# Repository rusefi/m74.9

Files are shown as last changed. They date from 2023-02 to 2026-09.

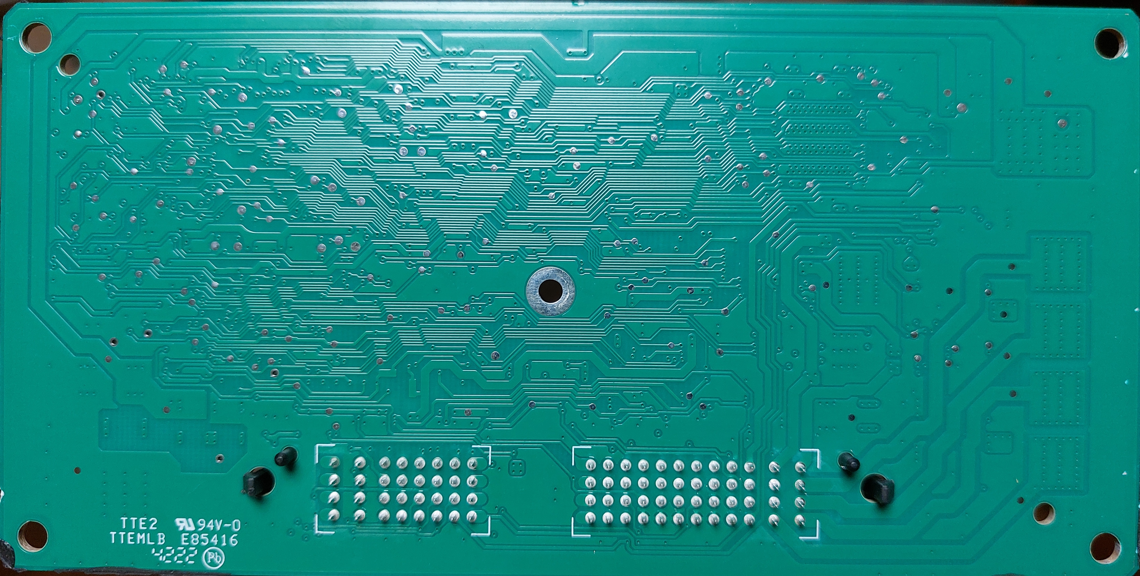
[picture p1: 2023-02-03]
hardware/photos/back.jpg

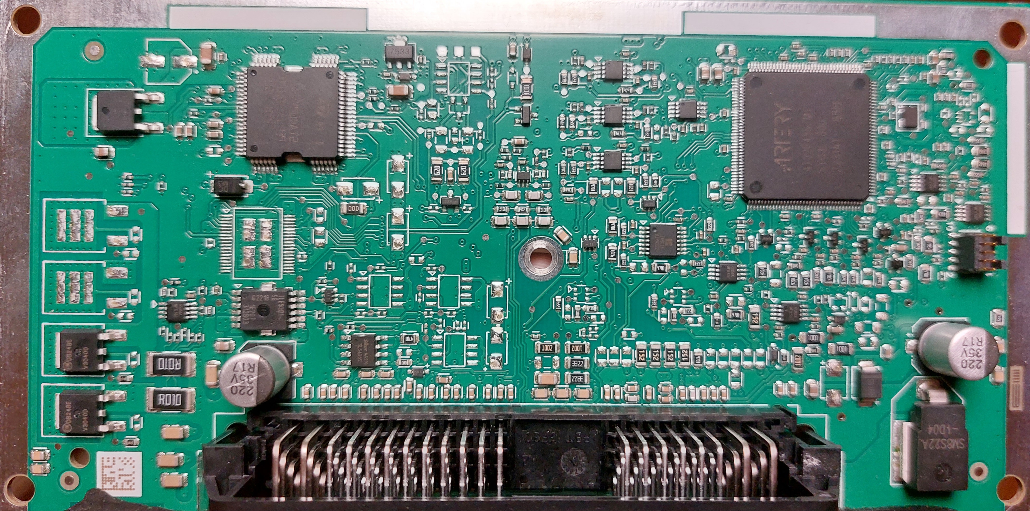
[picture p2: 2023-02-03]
hardware/photos/front3.jpg

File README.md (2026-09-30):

# m74.9

Reverse engineering of m74.9 ECU using KiCad EDA

[Interactive Pinout](https://rusefi.com/docs/pinouts/m74.9/)

See also https://github.com/rusefi/S105

* 8450086873 Niva
* 8450086874 Niva
* 8450110707 Granta (wasted spark)
* 8450043732 Vesta NG (individual spark) 
* 259.3765 004-01 Gaz
  
## Инструкции по разборке

Помимо очевидных четырёх винтов, 🔴пятый винт🔴 прикрепляет печатную плату к НИЖНЕЙ половине корпуса. Рекомендуем сначала сломать клей по периметру корпуса, а потом отделить основной разъём от верхней половины корпуса. Нагрев феном очень помогает!

WhatsApp Image 2024-01-13 at 11 08 42_85430087

WhatsApp Image 2024-01-13 at 11 15 42_073bf53d

## PCB

[Higher resolution photos click here](https://github.com/rusefi/m74.9/tree/main/hardware/photos)









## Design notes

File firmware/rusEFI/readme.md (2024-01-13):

See https://rusefi.com/build_server/rusefi_bundle_m74_9.zip

See https://github.com/rusefi/rusefi/tree/master/firmware/config/boards/m74_9

## flags

Itelma uses custom user system area flags e.g. "fuses".

rusEFI likes RAM we go with default user system area flags e.g. "fuses".

fuses-default.bin - default user area dump extracted from AT32F435-START with default RAM vs FLASH cache configuration:
384 Kb of RAM + 256Kb for cache for zero-wait flash

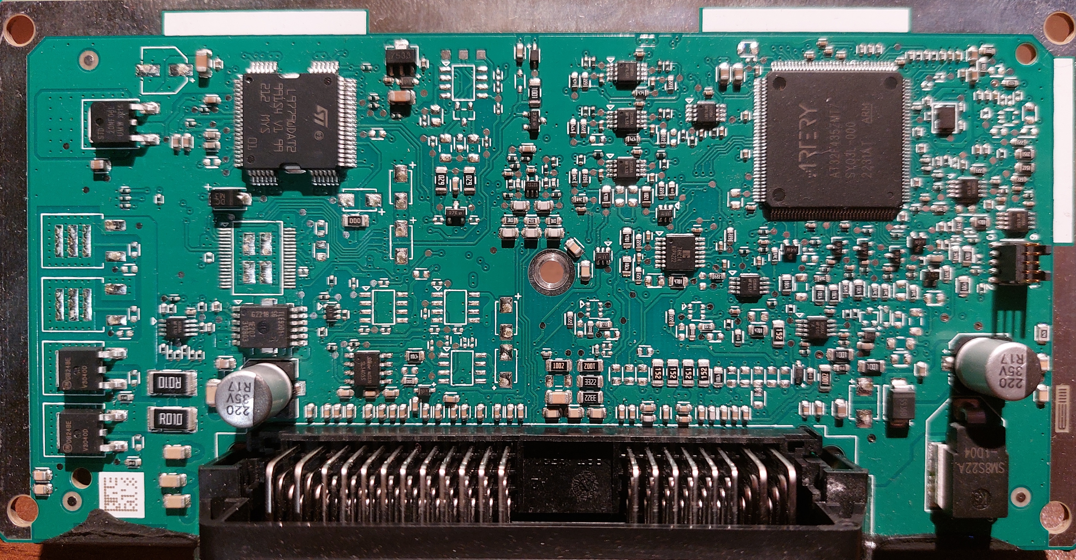
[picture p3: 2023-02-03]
hardware/photos/front1.jpg

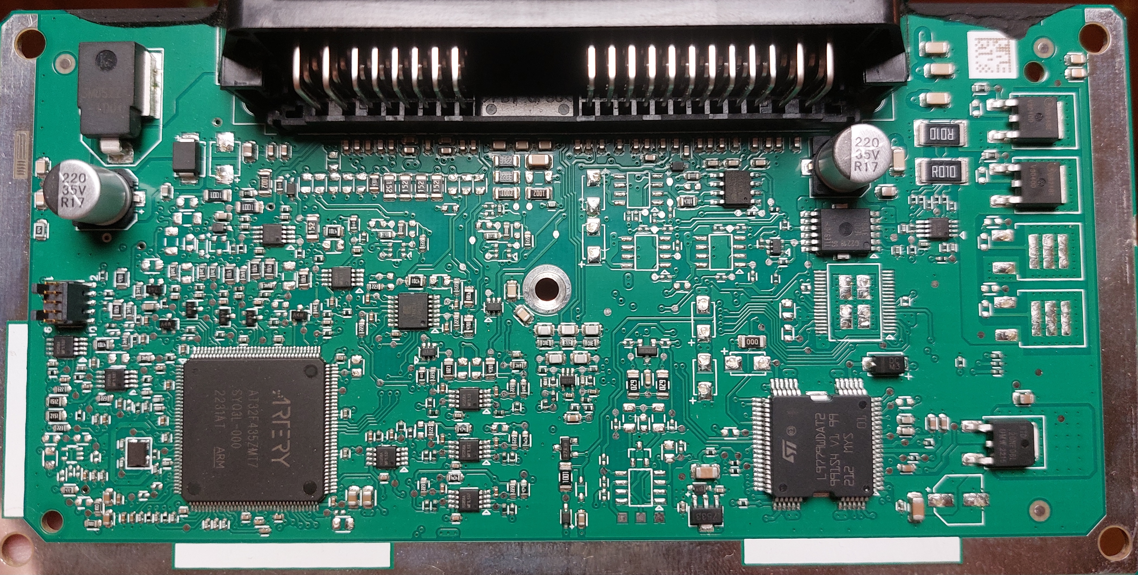
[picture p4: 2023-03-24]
hardware/photos/front2.jpg

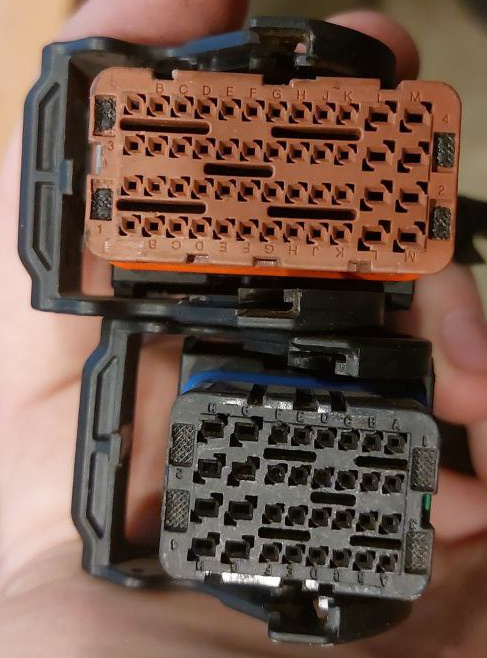
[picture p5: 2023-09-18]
oem-plugs.jpg

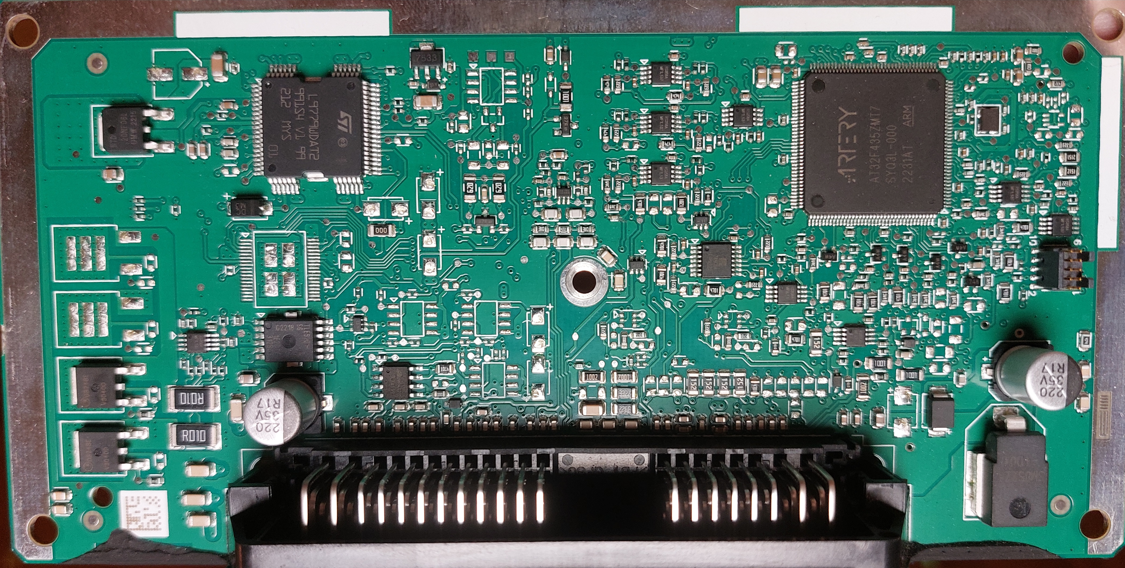
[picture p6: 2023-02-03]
m74.9_front_3.jpg

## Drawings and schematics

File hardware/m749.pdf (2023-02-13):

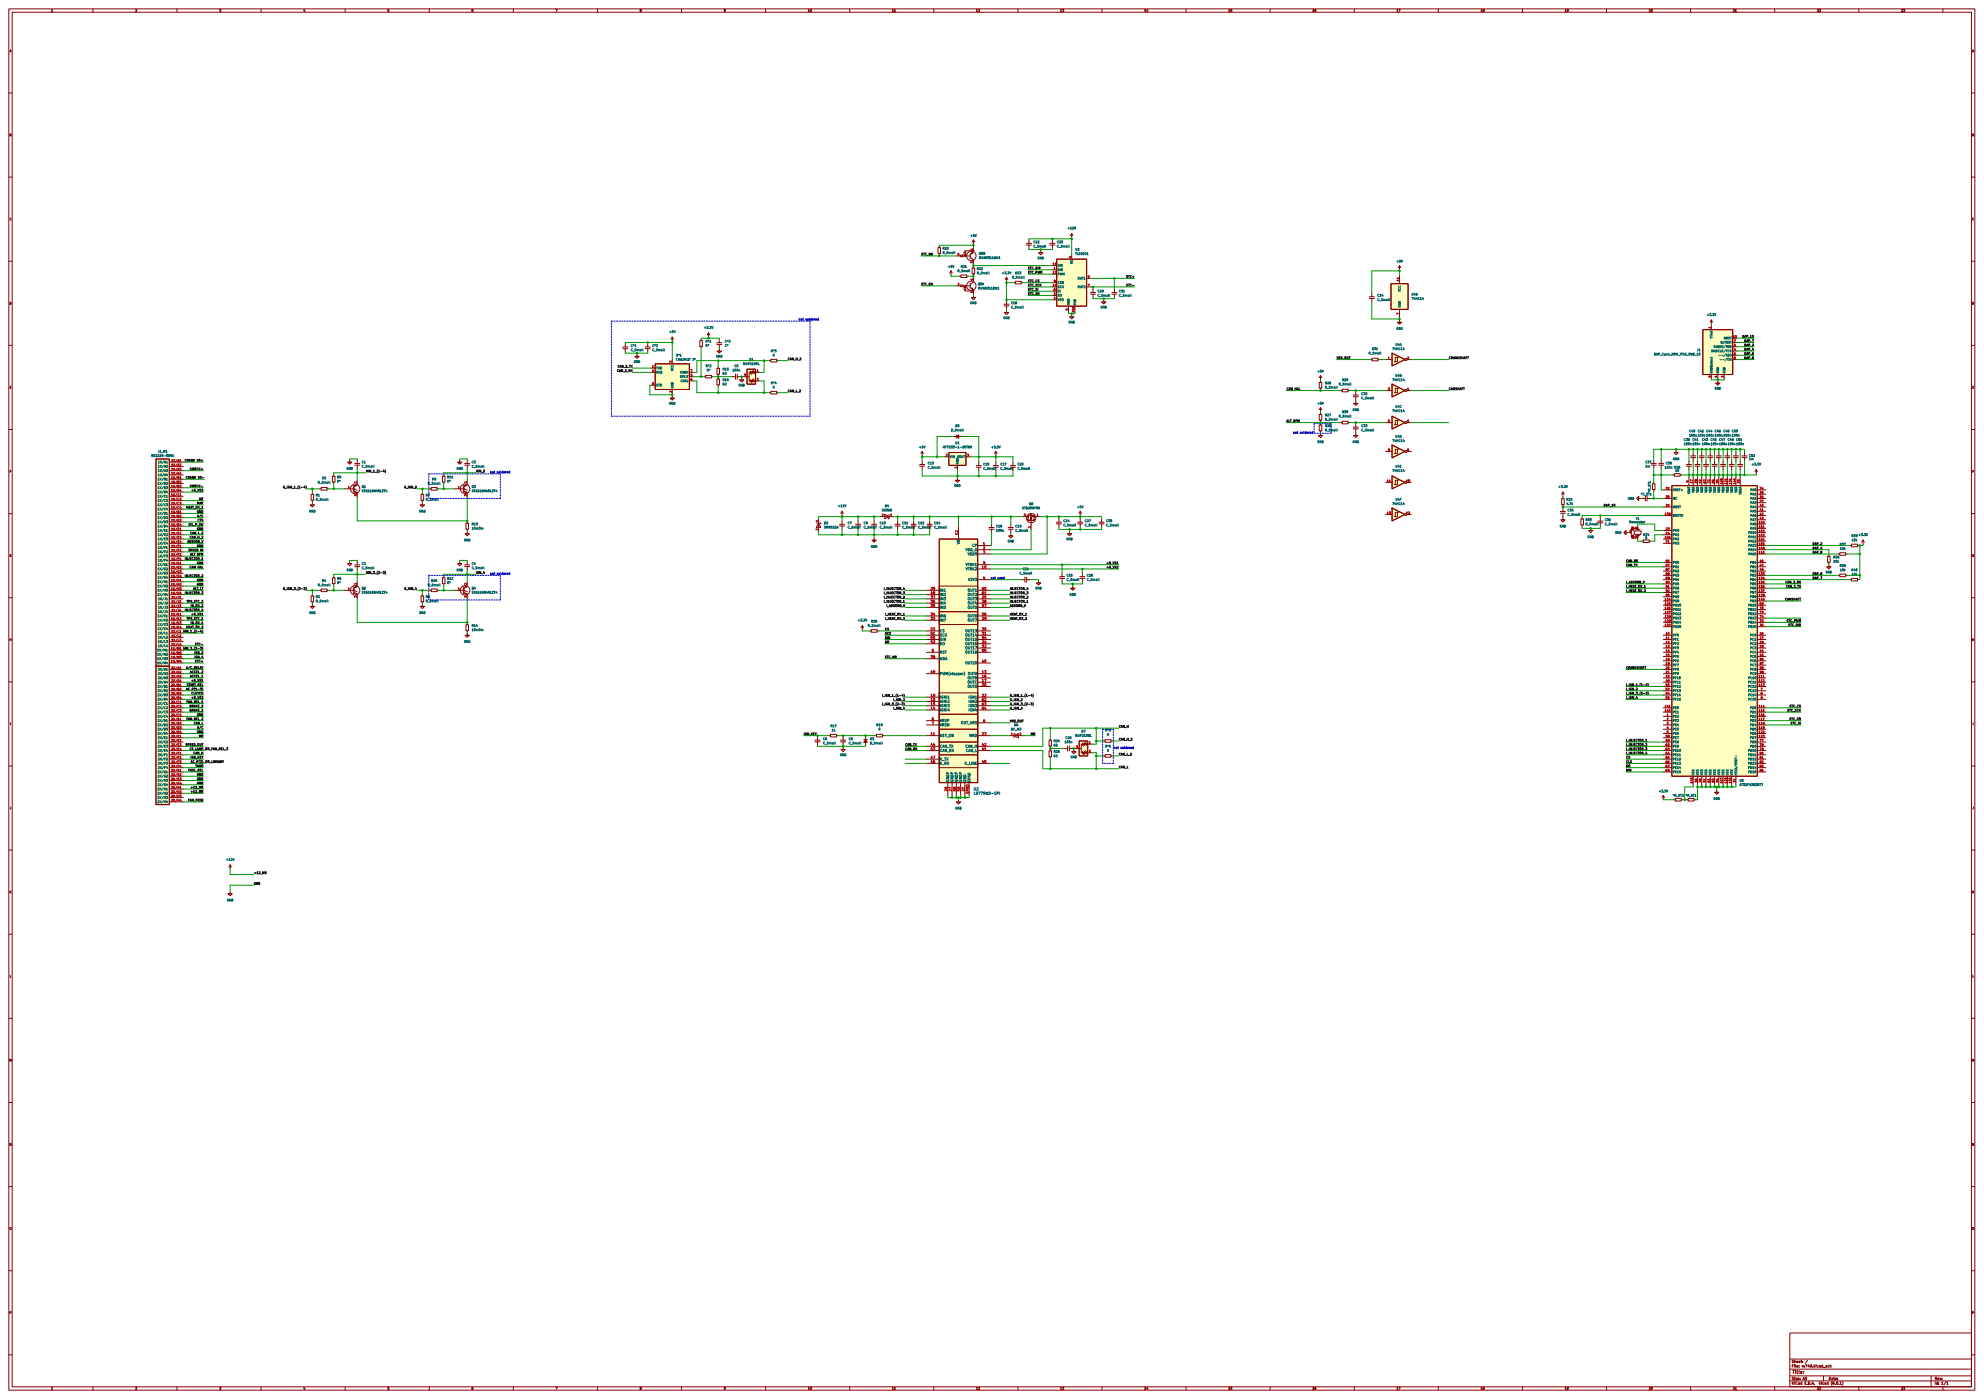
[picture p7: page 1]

IAT GND MAP CRANK VR+ CRANK VR- KNOCK+ KNOCK- HEAT_OX_1 A/C

OUT4 | 25 GNDP 26 GNDP 27

64 VRSN

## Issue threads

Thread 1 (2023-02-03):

at32f435zmt7 is not 100% pin compatible with stm32

rusefillc, 2023-02-03:
at32f435zmt7 is not 100% pin compatible with stm32

i suggest we start with official stm32 symbol and make changes to highlight all the pins which differ

rusefillc, 2023-02-04:
at32f435zmt7 отличается от stm32f437zit6 в пяти местах
30 stm - vdd, at - nc
31 stm - vssa, at - vssa/vref-   (тут считай не отличается)
71 stm - vcup1, at - ph3
106 stm - vcup2, at - ph2
143 stm - pdr_on, at - vss

остальное совпадает

rusefillc, 2023-02-04:
143 нулисторами выбирается масса или питание
71 и 106 да, есть место

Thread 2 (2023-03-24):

looking to reimplement CAN bootloader protocol

rusefillc, 2023-03-24:
End dream is to take OEM ECU from real vehicle and flash it with rusEFI bin using OEM bootloader

Would be also great to have a way to flash it back from rusEFI into original state

rusefillc, 2023-03-24:
We have a lot of files at https://github.com/rusefi/m74.9/tree/main/firmware/oem

@esaulenka poke :)

esaulenka, 2023-04-14:
To be able to use same bootloader and same C___loader application, rusEfi sould:
- use addresses 08001000 .. 080FF000 (with standard vector tables located at 08001000)
- dont (!) use RAM at 20019800..2001B148 (at least, when VendorSpecific diagnostic session is open)
- support UDS protocol, at least services 10, 11, 22, 27, 31 (need more investigations for it), 34, 36, 37
- able to start bootloader when Programming diagnostic session is opened (some details in RE_notes doc)

To make one-way operation (i.e. flashing rusEfi without further update by original boot) only first point is needed.

moonglow, 2023-04-28:
About custom services for "ReadFW" and  some others log data from `M74_9 fw update traces 1.xlsx` using special service tool.

Service software checks if service `0x1A` is exist and if not ( ECU gives back NRC ) load ARM code to RAM ( at: 2001_9800 ) via WRITE_MEMORY_BY_ADDRESS ( 0x3D ) service and RUN that payload via ROUTINE_CONTROL ( 0x31 ) service. Payload itself encrypted, but  it also has start function that will decrypt it in-place and run. Payload install their own handlers on some services:

0x11 - ECU_RESET
0x1A - SERVICE_TOOL_SPECIAL_SERVICE
0x23 - READ_MEMORY_BY_ADDRESS
0x27 - SECURITY_ACCESS
0x31 - ROUTINE_CONTROL
0x3D - WRITE_MEMORY_BY_ADDRESS
0x3E - TESTER_PRESENT

Why it needs ?

1. All service packet body ( except service ID ) is encrypted now ( with something like RC4 )
2. Seed/Key auth is changed to md5 based
3. New service `0x1A`
```
> 0x1A 0xC1
< 0x1A 0xC1 XX XX XX XX DD DD DD DD
```

where:
0xC1 - is constant and checked by payload handler
XX XX XX XX - content of CPUID register ( E000_ED00 )
DD DD DD DD - content of DEBUGMCU register ( E004_2000 ) and looks like it used to prevent using service tool while target under debugger

moonglow, 2023-04-28:
More about service tool seed/key auth algo with example from our current ReadFw logs:

Auth part with service payload is here:
```mono
45.257: >SECURITY_ACCESS REQUEST_SEED => 7B 7B E8 02 [RND]
45.258: <SECURITY_ACCESS REQUEST_SEED <= 03 EA 00 0A [SEED]
45.261: >SECURITY_ACCESS SEND_KEY => 8C 84 A1 77 [KEY]
45.261: <SECURITY_ACCESS SEND_KEY
```
Pseudocode:
KEY = MD5( RND + SEED + CONST )[7:4]

*RND & SEED reads to variable as big-endian values, so it will actually stores as reverse ordered in memory inside our ECU
*CONST - this is byte array ( actually this is service tool ascii string ident ): `28 63 29 20 53 4D 53 2D 53 6F 66 74`

So we need to calculate MD5 hash over this data:
`02 E8 7B 7B    0A 00 EA 03    28 63 29 20 53 4D 53 2D 53 6F 66 74`
MD5 hash result ( we need only 4 bytes from offset 7 ):
`D462F61426DD58 8C84A177 B8C9F5A2E3`

moonglow, 2023-04-28:
About service body data encryption. Service payload uses RC4 stream cipher. As example you can find core algo [here](https://github.com/WaterJuice/WjCryptLib).

To init cipher we need to calculate some needed data: initial key, drop first data counter

Pseudocode:
RC4_KEY = MD5( CONST + SEED + CODE_BYTES + RND + KEY_HASH )
DROP_COUNT = ((SEED ^ (SEED>7)) & 0x1FF) + 0x200

*CONST - this is byte array from previous part, but now it used in full 22 bytes form in our case: `28 63 29 20 53 4D 53 2D 53 6F 66 74 20 41 54 33 32 46 34 44 72 76`
*SEED & RND - from previous part
*CODE_BYTES - just bunch of bytes of our payload code area, in our case: `0A 0A EB 08 08 4F EA B8 28 08 EB 03 08 08 EA 01`
*KEY_HASH - full MD5 key hash from previous part

Lets combine it all together:

Calculate rc4 key ( total size: 62 bytes ):
`28 63 29 20 53 4D 53 2D 53 6F 66 74 20 41 54 33 32 46 34 44 72 76` - signature
`0A 00 EA 03` - seed
`0A 0A EB 08 08 4F EA B8 28 08 EB 03 08 08 EA 01` - code area data
`02 E8 7B 7B` - rnd
`D4 62 F6 14 26 DD 58 8C 84 A1 77 B8 C9 F5 A2 E3` - auth key md5 hash

MD5 hash result ( used as RC4 key ):
`B0 14 27 A1 9B 56 A3 12 FC 7C 83 B9 C9 AB D8 76`

Calculate drop count from seed:
`((03EA000A ^ (03EA000A>>7)) & 0x1FF ) + 0x200 = 0x20A`

Now we able to decode/encode all encrypted data from our logs, example:

Raw log data:
```C
45.306: >ROUTINE_CONTROL, data: 3F B6 C7 D8 AA 1C 56 0F 04
45.306: <ROUTINE_CONTROL, data: 61 C9 94
45.307: >READ_MEMORY_BY_ADDRESS, data: 30 14 FC 05 BD 70
45.309: <READ_MEMORY_BY_ADDRESS, data[4084]: 24 71 81 D3 4C 70 D1 15 C6 55 0C 79 69 64 A2 CA
45.447: >ROUTINE_CONTROL, data: 44 2A 55 BE 59 F8 16 EF B1
45.447: <ROUTINE_CONTROL, data: 7A 85 D3
45.448: >READ_MEMORY_BY_ADDRESS, data: 6B 1E 66 6F 0A D6
45.450: <READ_MEMORY_BY_ADDRESS, data[4084]: 1C 01 A3 F3 D9 29 AF 03 47 60 A2 84 7E 4C 23 1C
45.588: >ROUTINE_CONTROL, data: 8A 5A 64 E4 53 86 86 49 E5
45.588: <ROUTINE_CONTROL, data: 0E 6B 56
```
Log data with RC4 cipher applied to service body ( now it does not looks like random bytes ):
```C
45.306: >ROUTINE_CONTROL, data: BC 08 00 10 00 00 00 0F F0
45.306: <ROUTINE_CONTROL, data: BC DA 00
45.307: >READ_MEMORY_BY_ADDRESS, data: 08 00 10 00 0F F0
45.309: <READ_MEMORY_BY_ADDRESS, data[4084]: 08 00 10 00 00 00 00 00 01 00 08 08 1B E9 0A 08
45.447: >ROUTINE_CONTROL, data: BC 08 00 1F F0 00 00 0F F0
45.447: <ROUTINE_CONTROL, data: BC DA 01
45.448: >READ_MEMORY_BY_ADDRESS, data: 08 00 1F F0 0F F0
45.450: <READ_MEMORY_BY_ADDRESS, data[4084]: 08 00 1F F0 01 2C 39 D1 78 BB 4B 1E DB B2 19 2B
45.588: >ROUTINE_CONTROL, data: BC 08 00 2F E0 00 00 0F F0
45.588: <ROUTINE_CONTROL, data: BC DA 0F
```

That's all folks!

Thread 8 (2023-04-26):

where to buy?

rusefillc, 2023-04-26:
https://www.avito.ru/all?q=8450086874
https://www.avito.ru/all?q=8450086873

rusefillc, 2023-05-18:
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

rusefillc, 2023-05-21:
https://avtoazbuka.net/products/ebu-kontroller-8450086873-m74-9-na-niva-legend-s-2022g-po-n-v

Нива Легенд 2023

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

rusefillc, 2023-05-23:
@dron0gus давай купим любые две штуки? 8450086873 и 8450086874 говорят ноль аппаратных различий

rusefillc, 2023-10-30:
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

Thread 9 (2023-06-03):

фото и yaml распиновки

rusefillc, 2023-06-03:
наверное мы хотим сделать аналогично https://rusefi.com/docs/pinouts/s105/

Внутри подписаны столбы буквами, ряды цифрами. Разъёмы зеркально подписаны, ну увидишь в общем.
Так вот в малом h1 и h2 любой это питание +12, f2 зажигание +12, g2 g3 g4 массы, f1 кан хай, d2 кан лоу.

rusefillc, 2023-10-30:
прогресс в https://rusefi.com/docs/pinouts/m74.9/

rusefillc, 2023-10-30:
page 63 of https://github.com/rusefi/rusefi_documentation/blob/master/OEM-Docs/Lada/ti_3100.25100.12052.pdf

rusefillc, 2023-11-27:
Done https://rusefi.com/docs/pinouts/m74.9/

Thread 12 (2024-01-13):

battery voltage input

rusefillc, 2024-01-13:
What do we know about battery voltage input? Which ADC using what schematics? Some resistor divider or else?

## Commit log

2023-02-04 at32f435zmt7 is not 100% pin compatible with stm32 #1
2023-02-07 I am just a secretary
    [m749.kicad_pcb, m749.kicad_sch]
2023-02-08 Add pdf file, update scheme.
    [m749.kicad_sch]
2023-02-10 update sheme
    [m749.kicad_sch]
2023-02-10 ADD TLE9201, ADD MUN5311, update sheme.
    [m749.kicad_sch]
2023-02-17 Update m749.kicad_sch
    partly ADC
    [m749.kicad_sch]
2023-04-13 fw update CAN traces
2024-01-13 local copy of https://github.com/rusefi/ChibiOS/blob/stable_20.3.x.rusefi_clean_history/demos/STM32/RT-AT32F435-ARTERY144/at32f4x.cfg
    [at32f4x.cfg]
2024-01-13 Update cfg
    [at32f4x.cfg]
2024-01-13 Scripts for changing fuses and writing RusEFI FW
2024-01-13 Fuses verify script
